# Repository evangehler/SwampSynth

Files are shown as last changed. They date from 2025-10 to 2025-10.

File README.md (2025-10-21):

# **SwampThing**
Beginning of a standalone Juno-106 inspired DCO monosynth for UF AES. Built around Raspberry Pi Pico Microcontroller.

## **Project Status**
| Component | Designed  | Prototyped  | PCB / Finalized |
| ----- | ---  | --- | --- |
| DCO Saw-core | X | X | |
| DCO Pulse / PWM | X | X | |
| DCO SUB | X | | |
| Blend | X | | |
| MIDI USB | | | |
| MIDI DIN | | | |
| VCF | | | |
| EG | | | |
| VCA | | | |
| Power Solution | | | |
| Output | | | |

# Table of Contents
- [Installation / Build](#installation--build)
  - [Prereqs](#prereqs)
  - [Build Steps](#build-steps)
  - [Quick Build & Flash](#quick-build--flash)
  - [Manual Flashing](#manual-flashing)
  - [Notes](#notes)
- [Architecture](#architecture)
  - [Component Diagram](#component-diagram)
  - [MIDI (DIN & USB)](#midi-din--usb)
  - [DCO (Core Oscillator)](#dco-core-oscillator)
    - [SAW](#saw)
    - [PULSE / PWM](#pulse--pwm)
    - [SUB OSC](#sub-osc)
  - [Power Solution](#power-solution)
- [Incomplete BOM](#incomplete-bom)

# Installation / Build
MIDI control, oscillator reset signals, charge voltage and envelope gates are derived from a Raspberry Pi Pico.

### Prereqs
- [VS Code](https://code.visualstudio.com/)
- [Raspberry Pi Pico VS Code Extension](https://marketplace.visualstudio.com/items?itemName=raspberry-pi.raspberry-pi-pico)

### Build Steps
1. Clone this repo
2. Open the `src` folder in VS Code (not the root folder!)
3. Open a PowerShell terminal in VS Code
4. Run:
```powershell
mkdir build
cd build
cmake -G "Ninja" ..
cmake --build .
```
5. The `.uf2` file will be in `build/SwampThing.uf2`

### Quick Build & Flash
- Press `Ctrl+Shift+B` to build and flash in one step - nifty!

### Manual Flashing
1. Hold BOOTSEL on your Pico and plug it in
2. Drag `SwampThing.uf2` onto the Pico drive

### Notes:
- Clock output: GPIO 13
- CV output: GPIO 14

# Architecture
## Component Diagram:
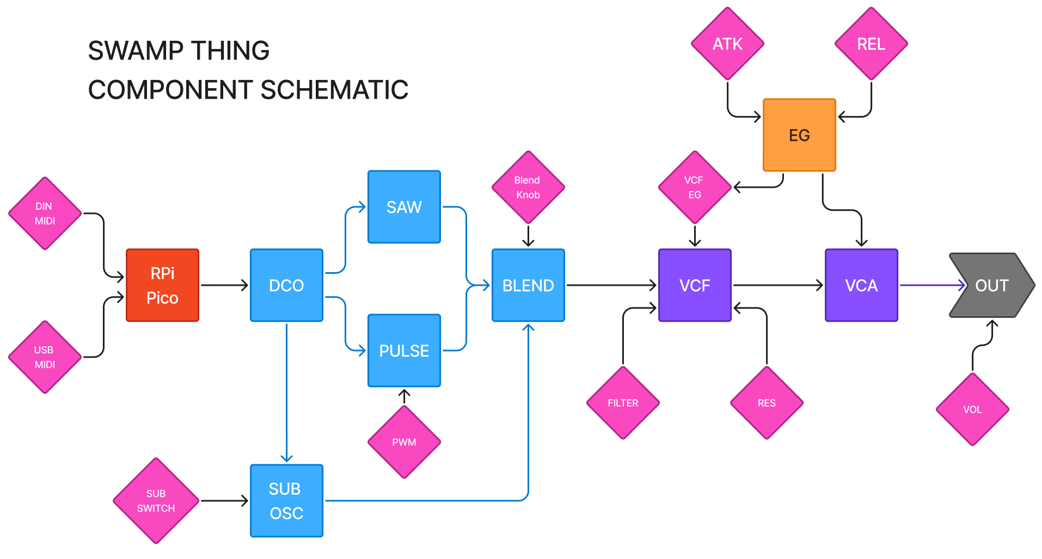
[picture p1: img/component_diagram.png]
Component Diagram


## MIDI (DIN & USB):
*Currently In Development*

## DCO (Core Oscillator):
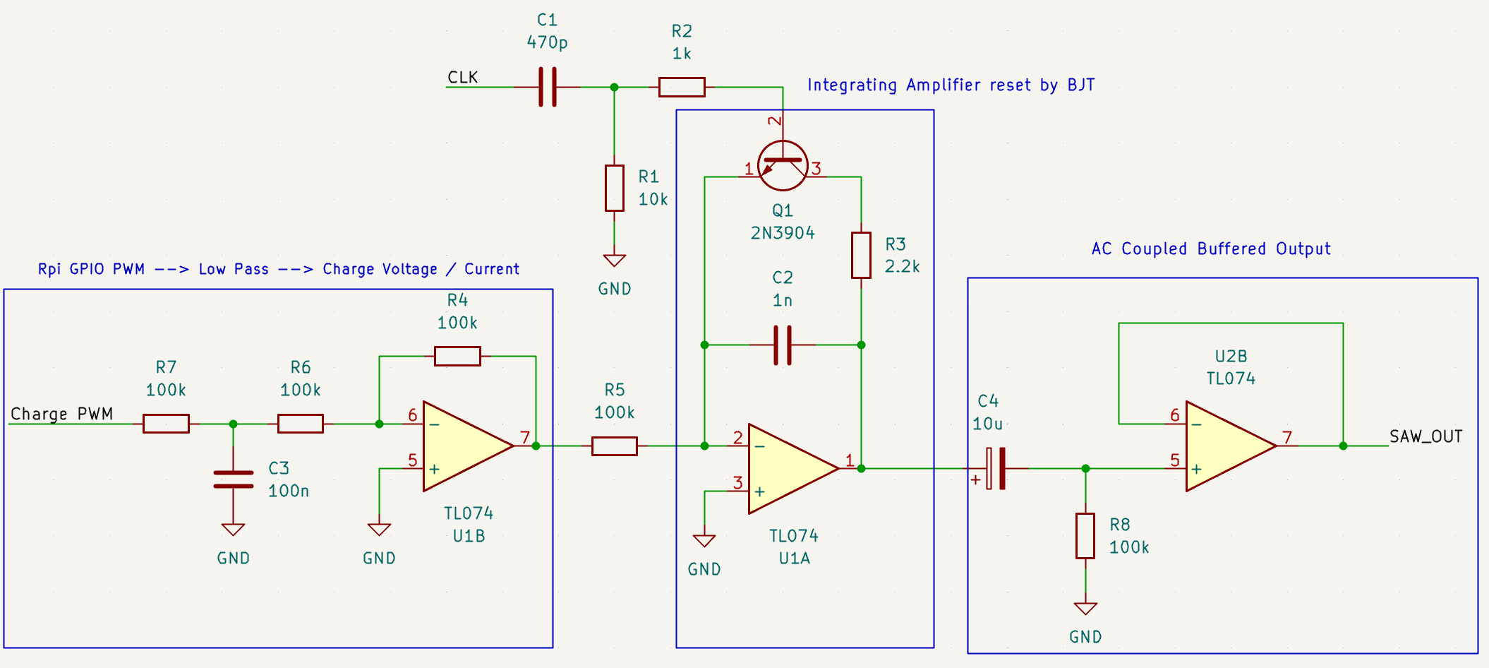
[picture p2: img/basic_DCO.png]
Basic DCO

### SAW
Juno-style ramp core. A TL074 op-amp integrator generates a rising ramp, NPN transistor reset discharges the timing capacitor at a rate set by the microcontroller clock. Pitch is set by the reset clock (GPIO 13). Ramp slope is set by a PWM-derived charge voltage filtered to DC (GPIO 14).

### PULSE / PWM
Saw --> Comparator, threshold = PWM

### SUB OSC
OSC --> Flip Flop, halves frequency

## Power Solution:
*Currently In Development*

 Presently planning +/- 12V, 5V rails.

# Incomplete BOM:

| PART | QTY | NOTE |
| ----- | ---  | --- |
| Raspberry Pi Pico | 1 | Micrcontroller |
| TL074 | 1 | 4x Op Amp |
| 2N3904 NPN BJT | 1 | Reset Transistor  |

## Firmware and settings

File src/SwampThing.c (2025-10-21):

#include <stdio.h>
#include "pico/stdlib.h"
#include "hardware/pwm.h"
#include <math.h>

#define CLOCK_PIN 13
#define CV_PIN    14
#define SYS_CLK   125000000.0f

#define MV_PER_HZ 0.00100f   // 440 Hz ≈ 560 mV
#define CURVATURE  -0.000000005f
#define V_SUPPLY  3.3f

// A4 = 440 Hz reference
#define A4_FREQ 440.0f
#define A4_MIDI 69   // MIDI note number for A4

void set_pwm_freq(uint gpio, float freq_hz) {
    uint slice = pwm_gpio_to_slice_num(gpio);
    uint chan  = pwm_gpio_to_channel(gpio);

    float clkdiv = 1.0f;
    uint32_t wrap = (uint32_t)((SYS_CLK / (freq_hz * clkdiv)) - 1.0f);
    if (wrap > 65535) {
        clkdiv = (SYS_CLK / (freq_hz * 65536.0f));
        wrap   = 65535;
    }
    pwm_set_clkdiv(slice, clkdiv);
    pwm_set_wrap(slice, wrap);
    pwm_set_chan_level(slice, chan, wrap / 2);
}

int main() {
    stdio_init_all();

    // --- CLOCK PWM ---
    gpio_set_function(CLOCK_PIN, GPIO_FUNC_PWM);
    uint slice_clk = pwm_gpio_to_slice_num(CLOCK_PIN);
    pwm_set_enabled(slice_clk, true);

    // --- CV PWM (~100 kHz carrier) ---
    gpio_set_function(CV_PIN, GPIO_FUNC_PWM);
    uint slice_cv = pwm_gpio_to_slice_num(CV_PIN);
    const float pwm_cv_freq = 100000.0f;
    float clkdiv_cv = 1.0f;
    uint32_t wrap_cv = (uint32_t)((SYS_CLK / (pwm_cv_freq * clkdiv_cv)) - 1.0f);
    pwm_set_clkdiv(slice_cv, clkdiv_cv);
    pwm_set_wrap(slice_cv, wrap_cv);
    pwm_set_enabled(slice_cv, true);

    const int low_note  = 48;   // C1
    const int high_note = 48;   // C2
    const int note_time_ms = 100; // 0.25 s per note

    while (true) {
        // Ascending chromatic
        for (int midi = low_note; midi <= high_note; midi++) {
            float freq = A4_FREQ * powf(2.0f, (midi - A4_MIDI) / 12.0f);

            set_pwm_freq(CLOCK_PIN, freq);

            float v_cv = MV_PER_HZ * freq + CURVATURE * freq * freq;
            if (v_cv < 0) v_cv = 0;
            if (v_cv > V_SUPPLY) v_cv = V_SUPPLY;
            float duty = v_cv / V_SUPPLY;
           
            pwm_set_chan_level(slice_cv, PWM_CHAN_A, (uint32_t)(wrap_cv * duty));

              printf("MIDI %d  |  %.3f Hz  |  Vcv = %.4f V  |  Duty = %.2f%%\n",
                   midi, freq, v_cv, duty * 100.0f);

            sleep_ms(note_time_ms);
        }

        // Descending chromatic
        for (int midi = high_note; midi >= low_note; midi--) {
            float freq = A4_FREQ * powf(2.0f, (midi - A4_MIDI) / 12.0f);

            set_pwm_freq(CLOCK_PIN, freq);

            float v_cv = MV_PER_HZ * freq;
            if (v_cv > V_SUPPLY) v_cv = V_SUPPLY;
            float duty = v_cv / V_SUPPLY;
            pwm_set_chan_level(slice_cv, PWM_CHAN_A, (uint32_t)(wrap_cv * duty));

              printf("MIDI %d  |  %.3f Hz  |  Vcv = %.4f V  |  Duty = %.2f%%\n",
                   midi, freq, v_cv, duty * 100.0f);


            sleep_ms(note_time_ms);
        }
    }
}

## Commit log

2025-10-19 added pico src files
2025-10-19 Update README
    Removed redundant mention of Pico being in BOOTSEL mode for the build and flash step.
2025-10-20 add kicad
    [swampthing.kicad_pcb, swampthing.kicad_sch]
2025-10-20 kicad fix
2025-10-20 chore(hardware): ignore KiCad backups/caches and untrack them
2025-10-20 Added basic DCO schematic
    [swampthing.kicad_sch]
2025-10-20 quick kicad
    [swampthing.kicad_sch]
2025-10-21 Pulse / PMW prototype, slight tweaks
